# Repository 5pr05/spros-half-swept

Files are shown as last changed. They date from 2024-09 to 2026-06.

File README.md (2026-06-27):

# Spros Half-Swept
A custom version of the [Sweep](https://github.com/davidphilipbarr/Sweep).

| Front | Back |
| --- | --- |
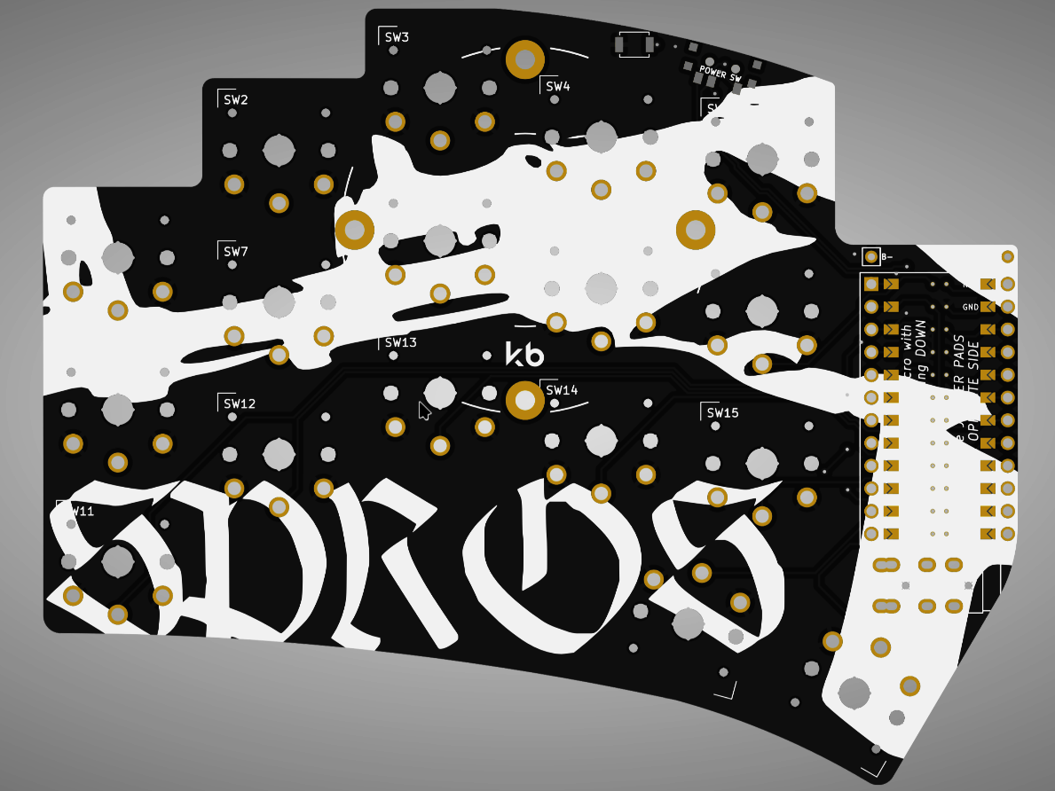
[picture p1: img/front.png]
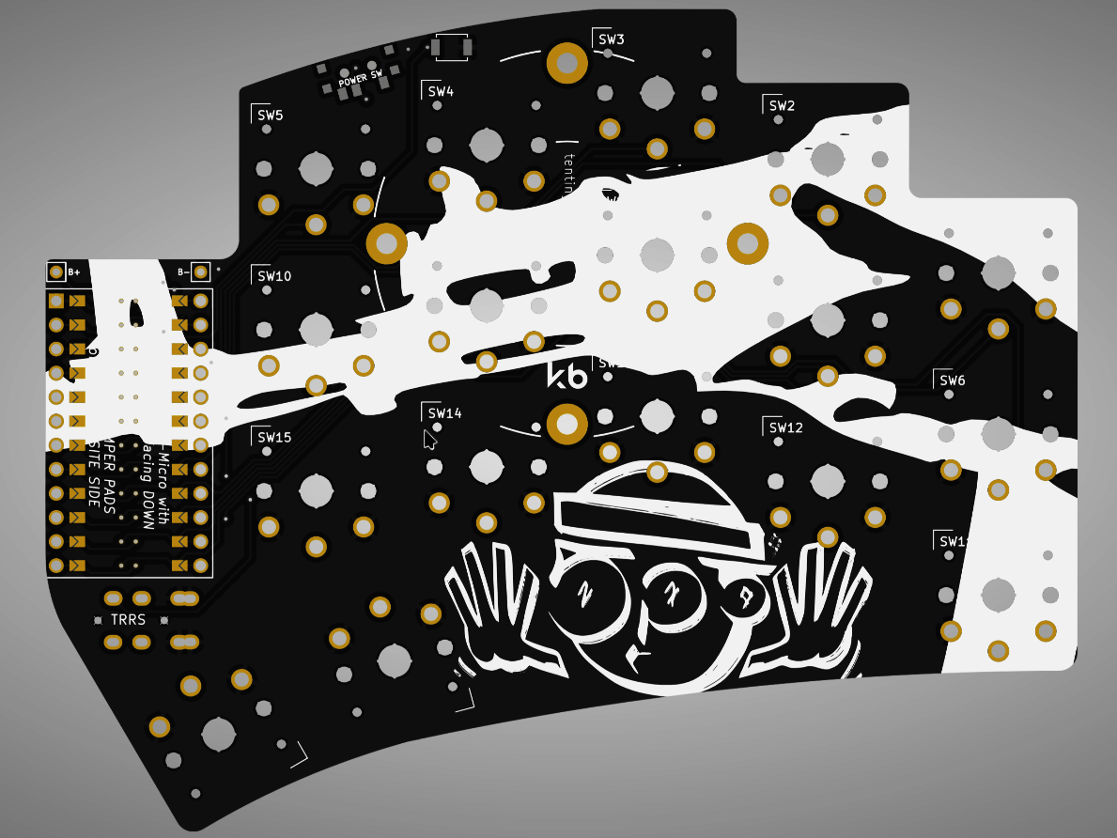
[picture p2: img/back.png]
|  |  |

Spros Half-Swept is a split keyboard based on the Ferris Sweep Half-Swept, which, in turn, is half of the Sweep2 modified for a reversible microcontroller footprint.

[Spros Half-Swept Case](https://www.printables.com/model/1472635-spros-half-swept-split-keyboard-case)

[Layout (Colemak DH)](https://github.com/5pr05/zmk-config-spros-half-swept)

[Build Process](https://youtu.be/D9_zCcpI5Xc)

## 5PR05 53TUP:

| Parts ordered from `Aliexpress` | Quantity |
| --- | --- |
| NRF52840 Controller | 2 pcs |
| Li-Po battery 30x35x5mm (or smaller) | 2 pcs |
| JST-XH Battery Connector Male and Female | 2 pcs |
| M2 insernut (7mm len, 3.18mm D2) | 10 pcs |
| M2 screws with small head (8mm len) | 10 pcs |
| Neodymium Magnets 8x2mm | 10 pcs |
| Kailh Choc Switches | 34 pcs |
| Blank MBK Choc Keycaps 1u | 34 pcs |
| Reset Buttons b3u, on/off switch msk12c02 | 2 pcs |
| TRRS jack | 2 pcs |
| Folding laptop feet | 2 pcs |

The goal of this build is to create a compact, low-profile keyboard that offers:
- Affordability
- Stylish design
- Comfort
- Practicality
- Easy portability
- Dual connectivity (Bluetooth and wired options)
  
## License & Credits

The Spros Half-Swept design retains the [SOLDERPAD HARDWARE LICENSE](https://github.com/davidphilipbarr/Sweep/blob/main/LICENSE).  
I would like to express my gratitude to all contributors of the Sweep project for their valuable contributions.

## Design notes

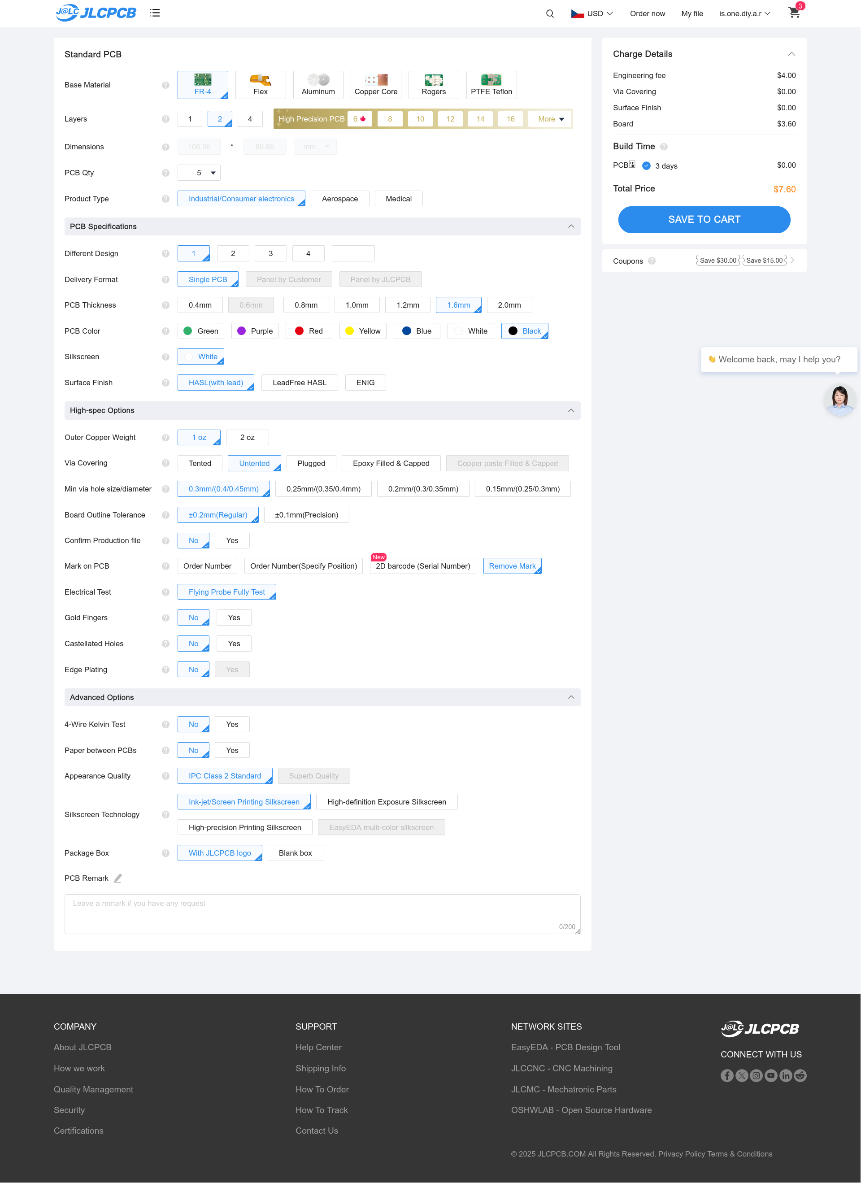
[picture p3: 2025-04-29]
img/pcb-settings.png

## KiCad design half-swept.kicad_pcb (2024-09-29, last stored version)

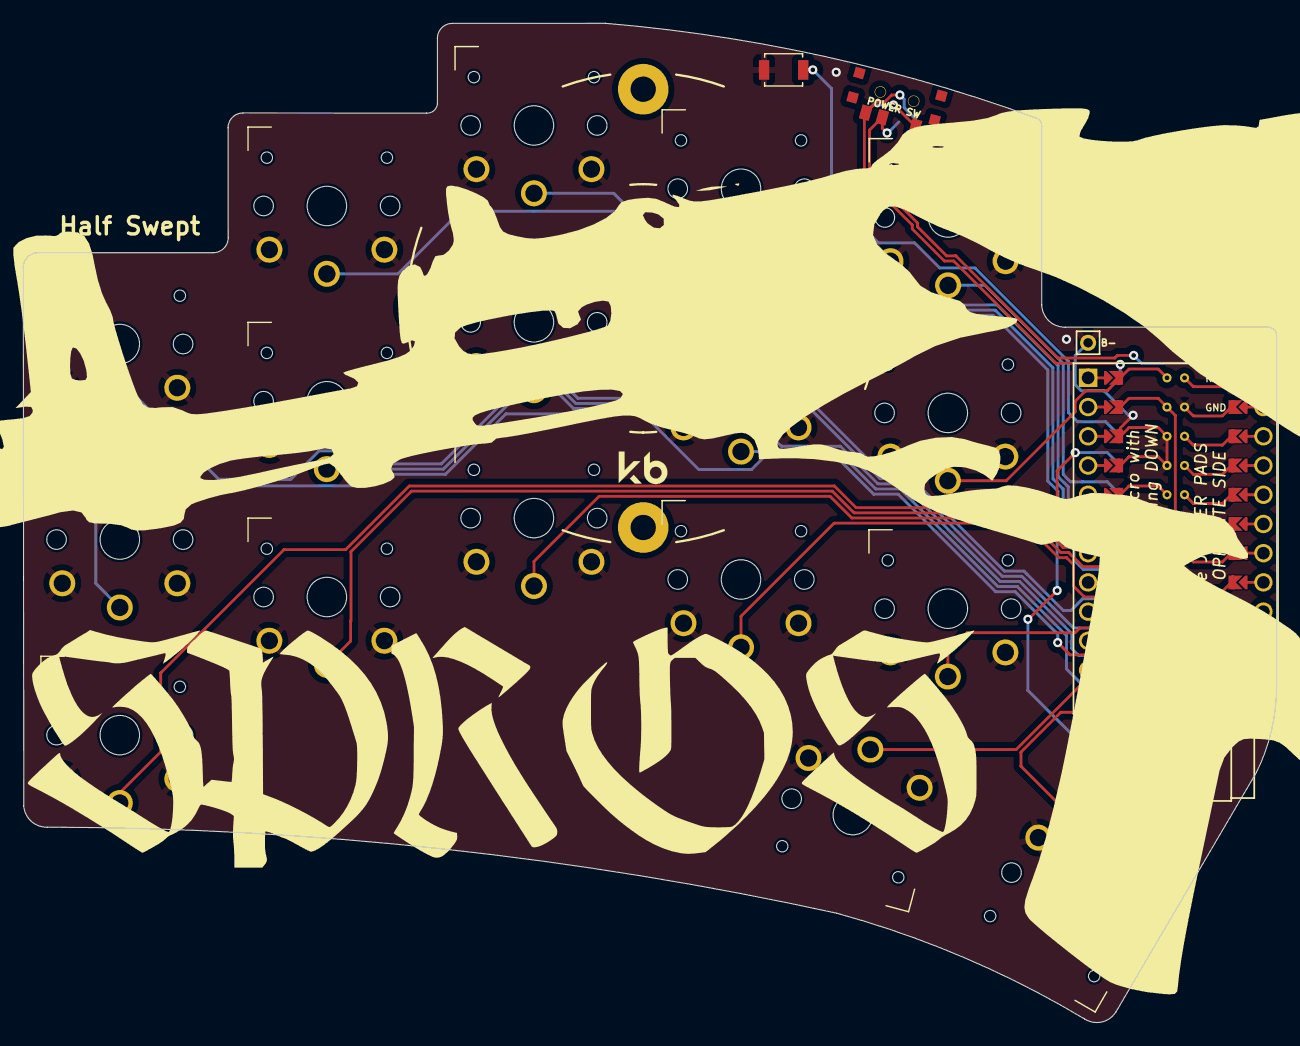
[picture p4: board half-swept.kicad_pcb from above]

Board: 2 copper layers, 109.0 x 86.9 mm, 23 parts (0 on the bottom side), 23 nets.

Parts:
B+: MountingHole_Pad; 1pin_conn
B-: MountingHole_Pad; 1pin_conn
J2: AudioJack4dpb; TRRS-PJ-DPB2
POWER SW: SW_SPDT; SPDT_C128955
RSW2: SW_Push; Tactile-Switch_SMT
SW1, SW2, SW3, SW4, SW5, SW6, SW7, SW8, SW9, SW10, SW11, SW12, SW13, SW14, SW15, SW16, SW17: SW_Push; SW_PG1350_rev_DPB
U1: ProMicro-kbd; ProMicro_jumpers_facedown

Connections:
BT+_r: B+.1, POWER SW.2
Switch1: SW1.1, U1.10
Switch2: SW2.1, U1.17
Switch3: SW3.1, U1.18
Switch4: SW4.1, U1.19
Switch5: SW5.1, U1.20
Switch6: SW6.1, U1.16
Switch7: SW7.1, U1.15
Switch8: SW8.1, U1.14
Switch9: SW9.1, U1.13
Switch10: SW10.1, U1.1
Switch11: SW11.1, U1.5
Switch12: SW12.1, U1.6
Switch13: SW13.1, U1.7
Switch14: SW14.1, U1.8
Switch15: SW15.1, U1.9
Switch16: SW16.1, U1.11
Switch17: SW17.1, U1.12
Switch18: J2.R1, U1.2
gnd: B-.1, J2.S, J2.T, RSW2.1, RSW2.2, SW1.2, SW2.2, SW3.2, SW4.2, SW5.2, SW6.2, SW7.2, SW8.2, SW9.2, SW10.2, SW11.2, SW12.2, SW13.2, SW14.2, SW15.2, SW16.2, SW17.2, U1.3, U1.4, U1.23
raw: POWER SW.3, U1.24
reset: RSW2.1, RSW2.2, U1.22
vcc: J2.R2, U1.21

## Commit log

2024-09-29 getting started: before ordering parts
    [half-swept-B_Cu.gbl, half-swept-B_Mask.gbs, half-swept-B_Paste.gbp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]
2024-11-26 case added
    [half-swept-B_Cu.gbl, half-swept-B_Mask.gbs, half-swept-B_Paste.gbp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]
2025-11-11 Update README to remove hot swap sockets
    Removed Mill-Max Hot Swap Sockets from the list.
2026-06-27 Revise Spros Half-Swept case links and add resources
    Updated links for Spros Half-Swept case and added layout and build process references.
